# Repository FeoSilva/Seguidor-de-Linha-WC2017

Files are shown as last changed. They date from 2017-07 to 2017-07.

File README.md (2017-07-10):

# Marcos John - Seguidor-de-Linha-WC2017
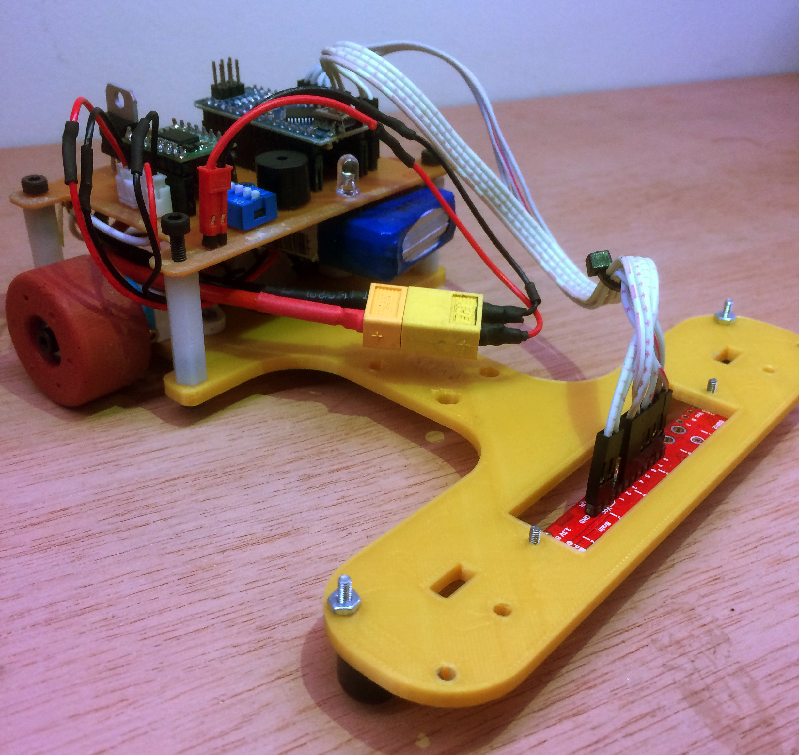
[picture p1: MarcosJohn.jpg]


O robô do Seguidor de Linha que participou do Winter Challenge edição 13 em 2017 está dividido em:
- Mecânica (Arquivos em CADs do robô projetado no SolidWorks 2016)
- Eletrônica (PCB projetada no Autodesk Eagle e confeccionada com a CNC OtherMill)
- Software (Programação do robô feita na IDE do Arduino)

Componentes do robô:
- Arduino Nano (Microcontrolador)
- <a href="https://www.pololu.com/product/960">QTR Array Analógico - Pololu (Sensor para Seguir Linha)</a>
- <a href="https://www.pololu.com/product/713">TB6612FNG - Pololu (Driver do Motor) </a>
- <a href="https://www.pololu.com/product/1098">50:1 Micro Metal Gearmotor LP 6V (Motores)</a>
- Bateria Li-Po 2S 7.4 - Turnigy

Agradecimentos: <br>
<a href="https://github.com/marcosdeoliveira">Marcos Oliveira</a><br>
<a href="https://github.com/joaopedrovbs">João Pedron Vilas Boas</a>

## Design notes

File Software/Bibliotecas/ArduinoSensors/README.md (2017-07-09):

# Arduino-Sensors

A "Library" of Libraries of Sensors. Infrared, Ultrasonic, Compass and many others,
ready to work with [ArduinoThread](https://github.com/ivanseidel/ArduinoThread) and fully object oriented.

This library was made to provide lot's of out-of-the-box features, such as 'Interfaces', 'Threadable' sensors,
and reliability over C++ Objects.

If you are a developer, please consider developing more sensor Libraries following the given pattern. I will be
pleased to incorporate it to the library!

## Installation

1. [Download](https://github.com/ivanseidel/ArduinoSensors/archive/master.zip) the Latest release from gitHub.
2. Unzip and modify the Folder name to "ArduinoSensors" (Remove the '-version')
3. Paste the modified folder on your Library folder (On your `Libraries` folder inside Sketchbooks or Arduino software).
4. Download and Install [ArduinoThread](https://github.com/ivanseidel/ArduinoThread)
5. Restart the Arduino IDE

## Included Generic Classes:

* AnalogIn
* DigitalIn
* DigitalOut
* AnalogVoltage

## Included Sensor Classes:

* MLX90614 Temperature Sensor
* HMC6352 Compass sensor
* EZ Ultrasonic Sensor
* Ping Ultrasonic Sensor
* HC-SR04 Ultrasonic Sensor
* InvenSense IMU MPU9150
* InvenSense IMU MPU6050
* Sharp Infrared Short Distance Sensor (GP2D120XJ00F)
* Sharp Infrared Medium Distance Sensor (GP2Y0A21YK)
* Sharp Infrared Long Distance Sensor (GP2Y0A02YK0F)

# The Concept of this Library

If you are here, you are probably looking for some sensor library. Perhaps an Distance sensor, or a Compass sensor, or even a IMU sensor. What do they all have in common? They are all sensors, and do some measurement. Perhaps an Angle, or a Distance, or a Speed...

Some libraries uses functions and others use Classes witch are better to maitain and even to understand the code. This Library tries to create a patterns that allows others to create better Sensor libraries with it, while keeping method names generic and compatibility across multiple platforms. Also, Sensors extend from it's base the a Thread (from [ArduinoThread](https://github.com/ivanseidel/ArduinoThread) Library), allowing `async` fetch of sensor data pretty easily.

But to do all that, we must have a strong and nice Base to work with. For example: There are many platforms that are 3.3v, 5v and even 1.8V. How can we make it work with multiple ADC values? How can we make it simple to develop and to use? Continue reading and you will understand.

# Base Classes

Consists of a set of classes that helps another classes like `DigitalIn`, `AnalogIn`, `DigitalOut`, `AnalogVoltage`. 

Also contains a set of Interfaces such as `AngleInterface`, `DistanceInterface`, `TemperatureInterface`, `VoltageInterface`, used by different sensor types.

Let's say we have a new Temperature sensor, and we want to create a Library for it. What we expect to have:
* **Generic method names.** In this case, it would extend a `TemperatureInterface`, that has the method `getTemperature` and `readTemperature`
* **Caching it's value.** We should be able to both `read` it's value (actually fetch sensor data, read analog, communicate...), or `get` it's current value (basically, return what was read last, like a caching).
* **Work Asynchronously.** Implementing Thread from [ArduinoThread](https://github.com/ivanseidel/ArduinoThread) Library, we can make it read with a fixed timing, and  get it's value latter without further delay.

## Interfaces

Interfaces are a very good way of transforming your usual code into a more generic way. It's basicaly a set of methods and properties (variables), that a Class will inherit. For example, every class that extends `AngleInterface`, will have a method called `readAngle` and `getAngle`. If a new sensor library is created, that reads an angle (perhaps a potentiometer, Compass or even a encoder), it could inherit from this interface, and get those methods.

I will explain why it's good to use with an experience I had:

I was developing a complex robot, that would require multiple Distance Sensor types. That included two types of Infrared distance sensor, and one type of Ultrasonic sensor. I have developed this library thinking that whenever I needed, I could change the sensor in hardware for another, and it would still work. Shure that there are physical differences between them, but what I wanted was to work with multiple sensors without altering more than ONE line of code. I so I did it. We could test with different sensors, without taking so much time on software and also hardware.

We also used a IMU from Invensense, that has a Compass. After a while, we decide to change that for a simple Compass Sensor. Both of the sensors libraries was made by me, implementing it's `AngleInterface`.

## Base Classes

Base Classes are used by other classes, and also by you (if you want), providing a even more High Level approach for IO manipulation.

### DigitalIn Class

Provides a easy approach for manipulating a Digital Input pin:

```
DigitalIn myButton(9);

// Check if Pin is HIGH
if (myButton)...
  
// Check if Pin is LOW
if (myButton == LOW)...

// Reads it's value
boolean val = myButton.readValue();

// Get last read value
val = myButton.getValue();
```

Also, if you initialize it passing `true` as a seccond param, every read will be inverted:
```
DigitalIn myInvertedButton(10, true);

// Check if Pin is LOW
if(myInvertedButton)

// Read it's value (inverted)
myInvertedButton.readValue();
```

### DigitalOut Class

Used to manipulate Digital Output pins in a easy way.

```
DigitalOut myLed(13);

// Turns LED on
myLed = HIGH;
myLed.turn(HIGH);
myLed.turnOn();

// Turns LED off
myLed = LOW;
myLed.turn(LOW);
myLed.turnOff();
```

Like DigitalIn, if you assign an seccond parameter in it's initialization, it will automatically invert it's output
```
DigitalOut myLedInverted(13, true);

// Turns LED off
myLedInverted = HIGH

// You can also check it's istate like this:
if(myLedInverted == HIGH) ...
```

### AnalogIn Class

We usually need to use Analog Pins as Digital. Or even Read it's value multiple times. I usually consider a lot the timing of things, knowing every milisecond that is happening on my program. Because of that you might consider using this class instead of usual `analogRead` function.

```
AnalogIn myPot(A0);

// Reads it's value
val = myPot.read();

// Get it's cached value (does not reads ADC, only returns last value)
val = myPot.getValue();
```

One usual case, is setting a threshold to compare. We do it for you:

```
// Set threshold for 500
myPot.setThreshold(500);

// Check if below 500
if(myPot.belowThreshold())...

if(myPot == false)...

// Check if above 500
if(myPot.aboveThreshold())...

if(myPot == true)...
```

## AnalogVoltage Class

This is a nice step for next generations of Libraries, because there are many Analog Sensors around, that it's converted value should be mapped to a Voltage, not a ADC value. But that's a problem becoming larger today, since there are platforms that runs with 5v, others with 3.3v... And imagine, every single library thrying to work whit that (or not)?

```
AnalogVoltage myVoltimeter(A0);

// Read the voltage (in Volts)
float pinVoltage = myVoltimeter.readVoltage();
```

Well, you might be wondering: How does it do it's magic? The answer is pretty simple: **Preprocessor macros**.

In compiling time, we detect weather you are using a 3.3v or 5v platform, and set a definition called `ADC_DEFAULT_AREF`. We use it later to scale the ADC to a voltage. But keep calm, you can override that pretty easily, and allows you to create custom `linear` voltage in readers (Like a voltage divider, to read a battery voltage).

```
// 0 in ADC now means -5v. full ADC (1024) means 10v
AnalogVoltage myCustomVoltimeter(A0, -5, 10);

float pinVoltage = myCustomVoltimeter.readVoltage();
```

# Working toguether with ArduinoThread

Read more about [ArduinoThread](https://github.com/ivanseidel/ArduinoThread) here. It's a library I created to simplify complex softwares that requires multiple async tasks. Let's say:
* Read Compass every 50ms
* Read Distance Sensors every 70ms
* Read a button every 5ms
* Get battery voltage every 1 minute
* and so on...

If you want a REAL example of it working, take a look at our [2013 RoboCup Junior Soccer Robot code](https://github.com/ivanseidel/Robot-Soccer-2013/tree/master/Software/Soccer_v02).

The idea is that you can register Threads in ThreadController (a group of Threads), and let the system check if it should be runned. In that way, you just GET sensor values in your main code, without consuming time every time you need something.

```
// Create a new ThreadController that will run always
// (means it will check if it's threads should be runned everytime)
ThreadController threads(0);

// Create some sensors
DistanceInterface *myDist1 = new SharpLong(A0);
DistanceInterface *myDist2 = new SharpShort(A1);
TemperatureInterface *thermometer = new MLX90614(0x32);
AngleInterface *myCompass = new HMC6352();

// Each sensor has it's interval set to minimum possible
// or something good to work with (20ms - 70ms).

// But they ARE Thread objects, so you can make use of
// it's methods:

// Compass should be read every 60ms
myCompass.setInterval(60);

// Add to the thread controller
threads.add(&myDist1);
threads.add(&myDist2);
threads.add(&thermometer);
threads.add(&myCompass);

// Now, just call threads.run(); to automatically run what is needed
// (perhaps in a Timer Callback? or in Loop.. whatever)
loop(){
  threads.run();
  
  // Get the most recend value WITHOUT reading the sensor
  double currentAngle = myCompass->getAngle();
  float distance = myDist1->getDistance();
  [...]
}

```

## Rest of Documentation under development...

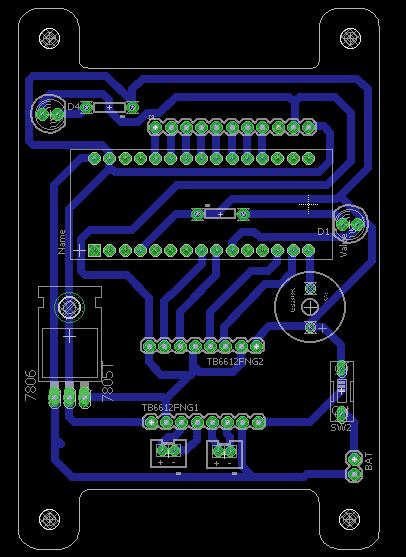
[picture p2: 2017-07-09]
Midia/PCB.JPG

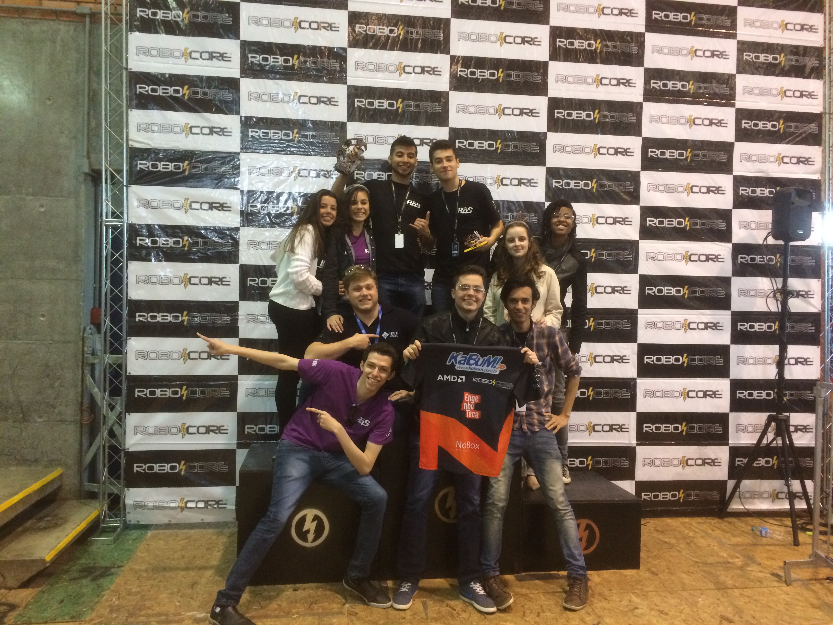
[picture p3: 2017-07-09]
Midia/Arquivo_001.jpeg

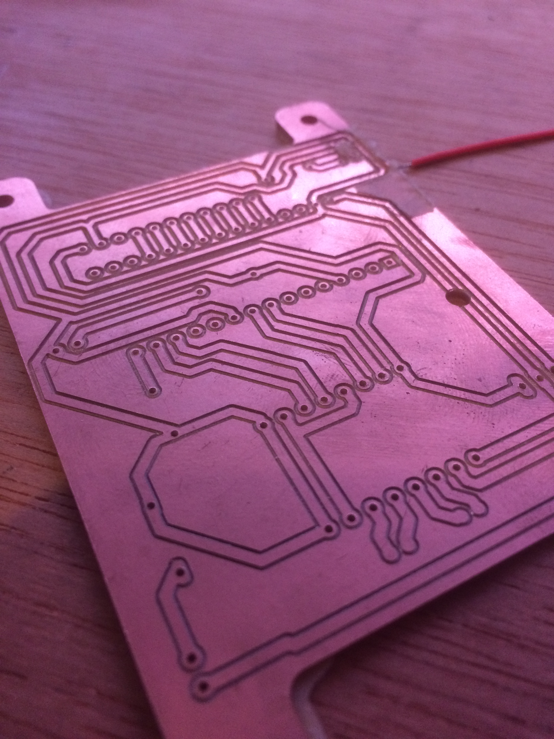
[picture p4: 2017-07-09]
Midia/Arquivo_000.jpeg

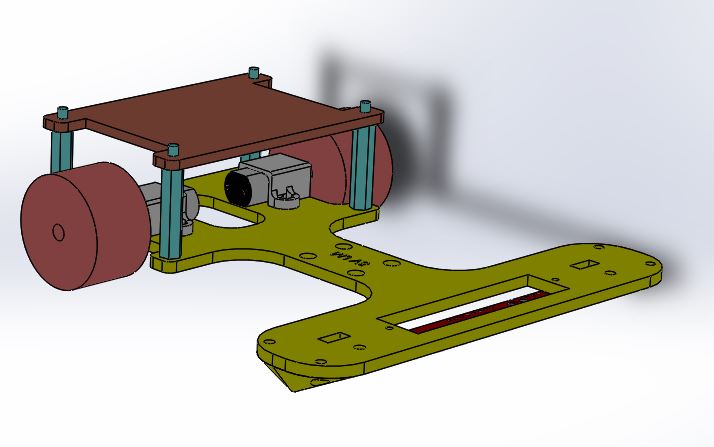
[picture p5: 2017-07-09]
Midia/Robot-3D.JPG

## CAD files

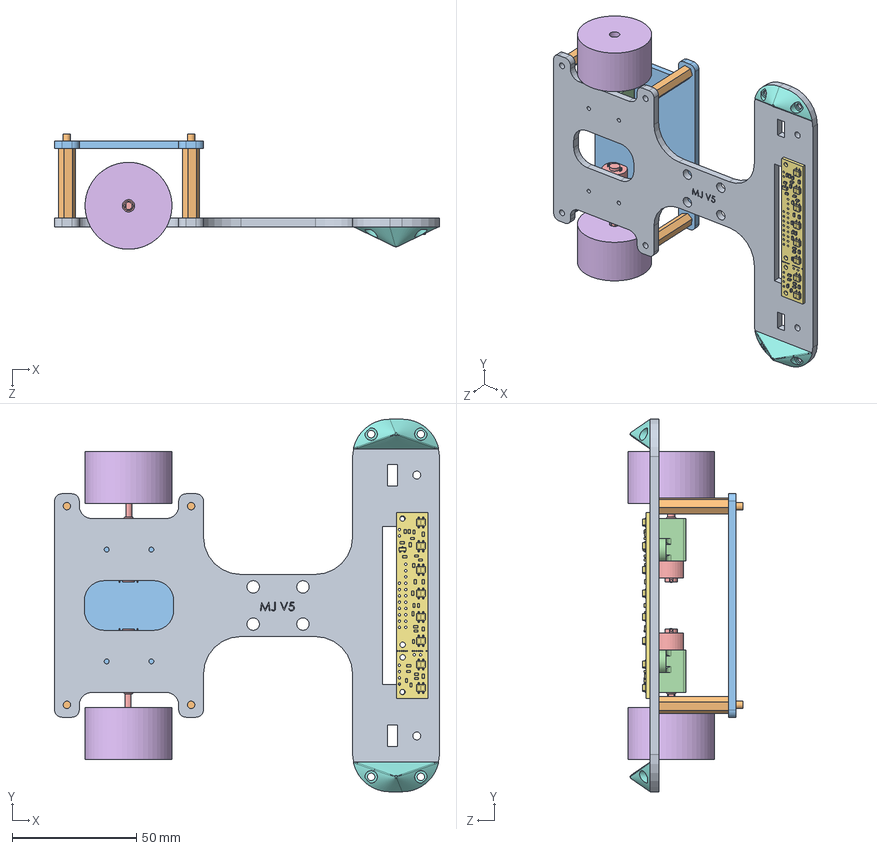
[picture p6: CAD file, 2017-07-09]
Mecânica/MJ V5/Robo completo.SLDASM
155.0 x 150.0 x 46.5 mm
PrincipalN
Standoff-Nylon x 4
PCB
Bracket Pololu x 2
Pololu #2218 Micro Metal Gearmotor HP(1) x 2
Rodas x 2
array oficial
ApoioN x 2

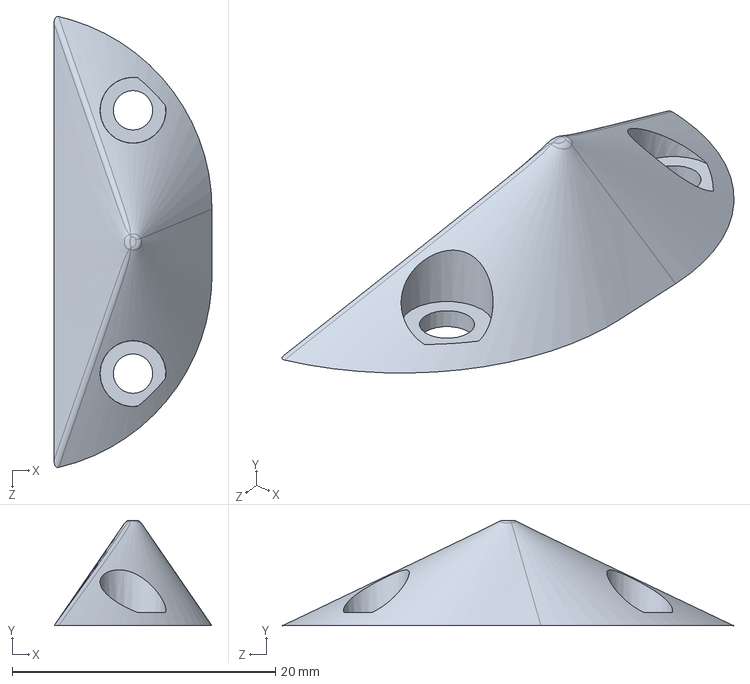
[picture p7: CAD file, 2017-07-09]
Mecânica/MJ V5/ApoioN.SLDPRT
12.0 x 8.00 x 34.3 mm

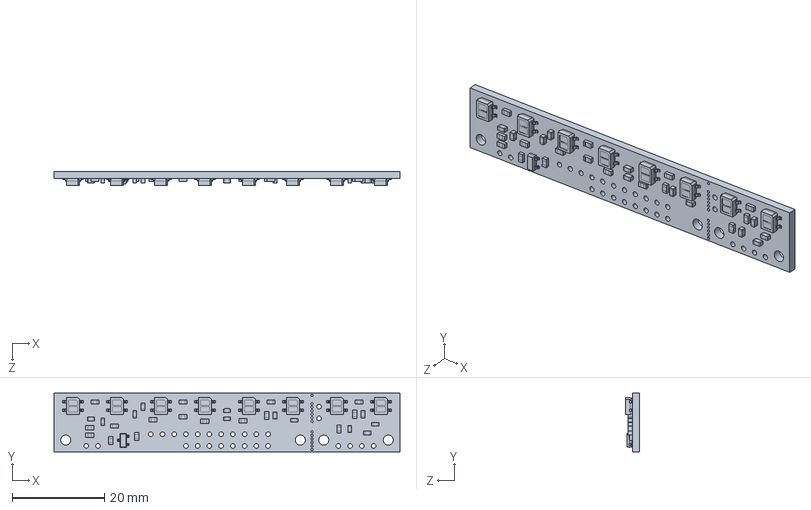
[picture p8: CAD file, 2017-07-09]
Mecânica/MJ V5/array oficial.SLDPRT
74.9 x 12.7 x 3.07 mm

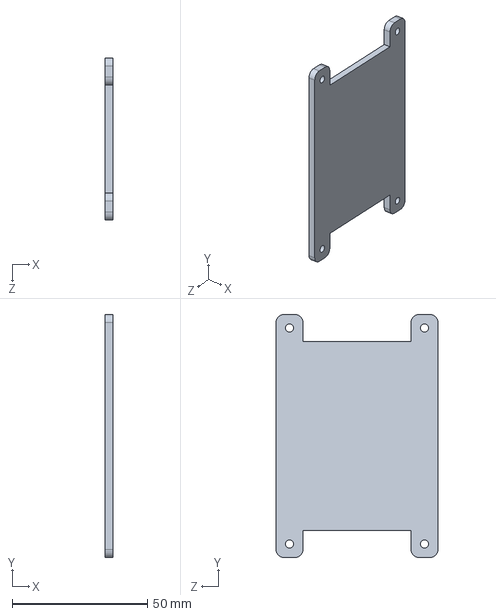
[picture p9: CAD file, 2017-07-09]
Mecânica/MJ V5/PCB.SLDPRT
3.00 x 90.0 x 60.0 mm

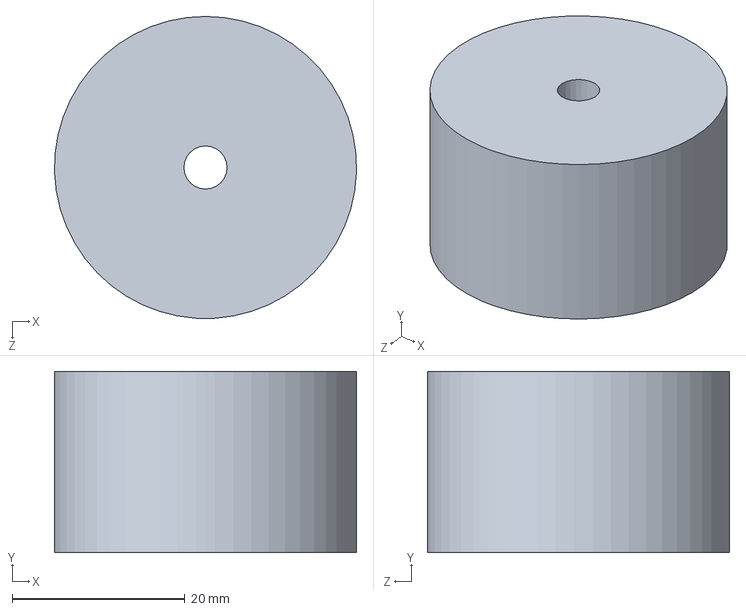
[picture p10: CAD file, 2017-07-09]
Mecânica/MJ V5/Rodas.SLDPRT
35.0 x 21.0 x 35.0 mm

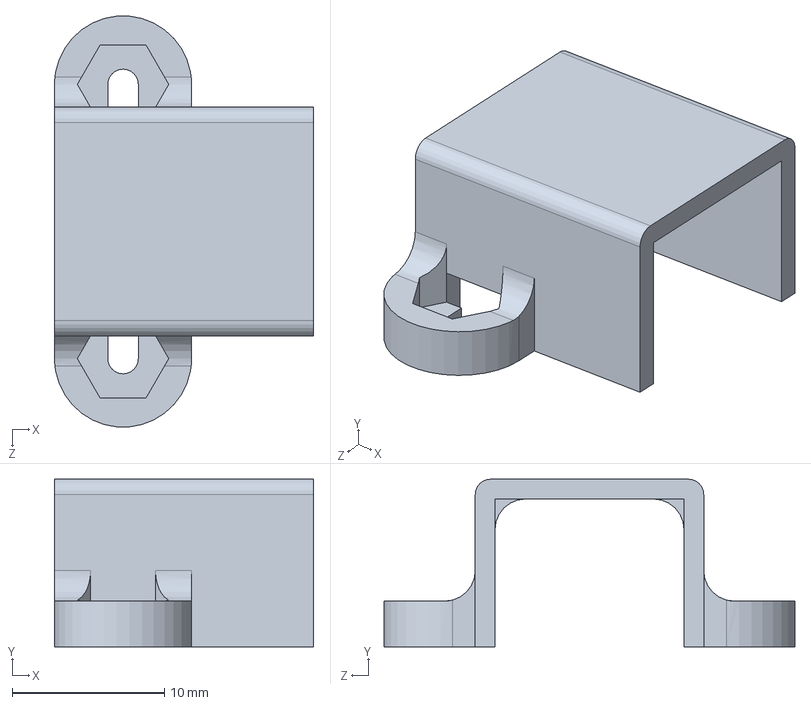
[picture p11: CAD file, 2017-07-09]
Mecânica/MJ V5/Bracket Pololu.SLDPRT
17.0 x 11.0 x 27.0 mm

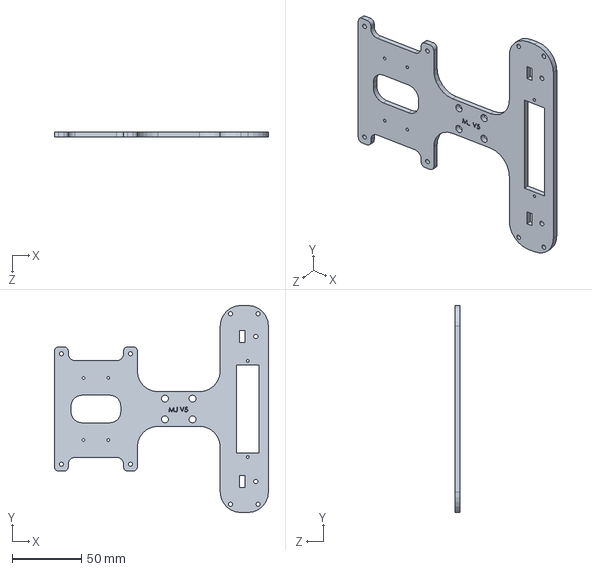
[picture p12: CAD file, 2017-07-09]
Mecânica/MJ V5/PrincipalN.SLDPRT
155.0 x 150.0 x 3.50 mm

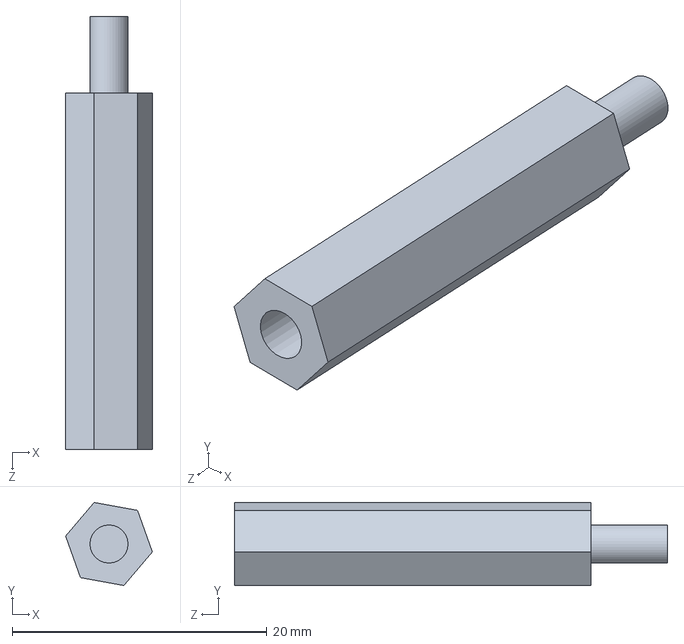
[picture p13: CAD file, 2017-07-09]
Mecânica/MJ V5/Standoff-Nylon.SLDPRT
6.82 x 6.52 x 34.0 mm

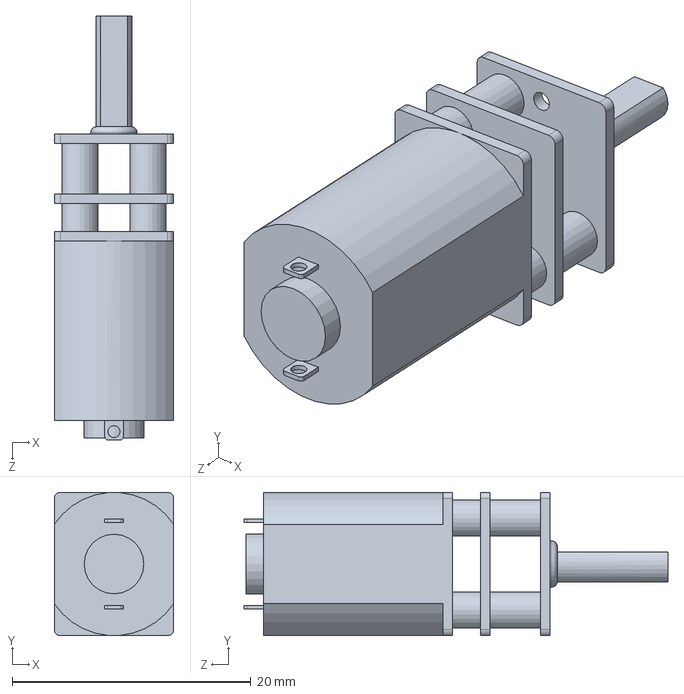
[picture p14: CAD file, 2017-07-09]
Mecânica/MJ V5/Pololu #2218 Micro Metal Gearmotor HP(1).SLDPRT
10.0 x 12.0 x 35.5 mm

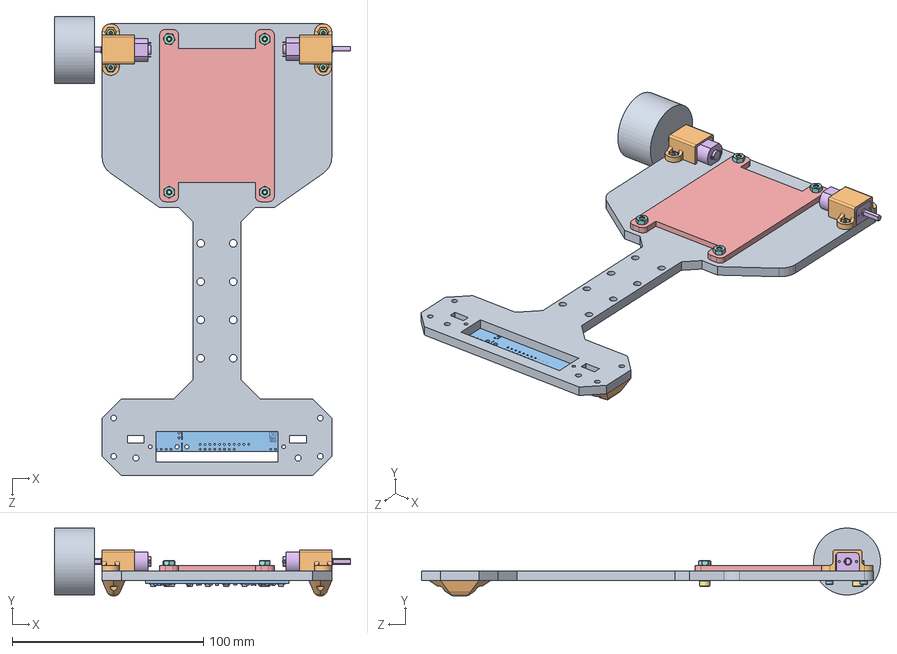
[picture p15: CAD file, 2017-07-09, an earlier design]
Mecânica/MJ V4/Montagem1.SLDASM
154.9 x 35.5 x 239.8 mm
Principal
Bracket Pololu x 2
M2 x 0.4mm Thread 8mm LONG SOCKET HEAD CAP SCREW x 4
M2 x 0.4mm Thread HEX NUT x 4
PCB
Pololu #2218 Micro Metal Gearmotor HP x 2
M3 x 0.5mm Thread 10mm LONG SOCKET HEAD CAP SCREW x 4
M3 x 0.5mm Thread HEX NUT x 4
Rodas
Apoio x 2
array oficial

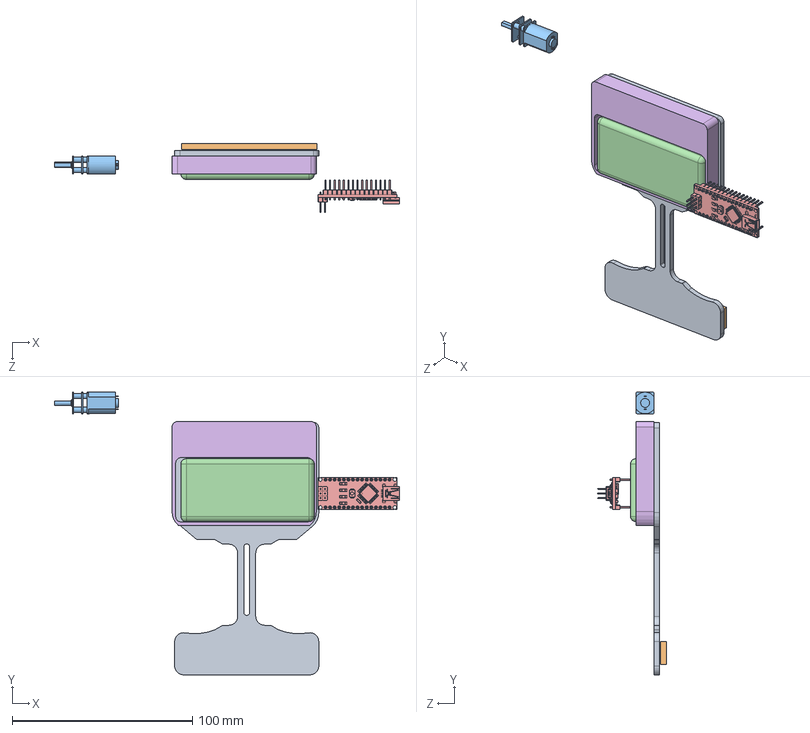
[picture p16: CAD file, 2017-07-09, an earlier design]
Mecânica/MJ V1/Montagem1.SLDASM
191.3 x 156.8 x 38.0 mm
LinhRaS
MicroMotor
Lipo
ArduinoNano
suporte

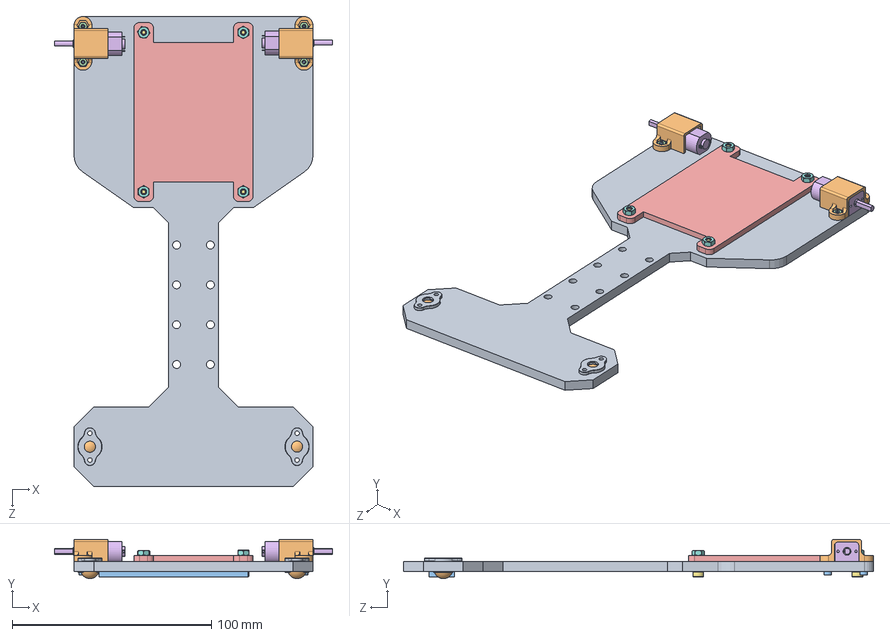
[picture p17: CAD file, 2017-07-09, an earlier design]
Mecânica/MJ V2/Montagem1.SLDASM
139.7 x 19.7 x 236.0 mm
Principal
Bracket Pololu x 2
M2 x 0.4mm Thread 8mm LONG SOCKET HEAD CAP SCREW x 4
M2 x 0.4mm Thread HEX NUT x 4
PCB
Pololu #2218 Micro Metal Gearmotor HP x 2
M3 x 0.5mm Thread 10mm LONG SOCKET HEAD CAP SCREW x 4
M3 x 0.5mm Thread HEX NUT x 4
Caster_1 x 2
Ball x 2

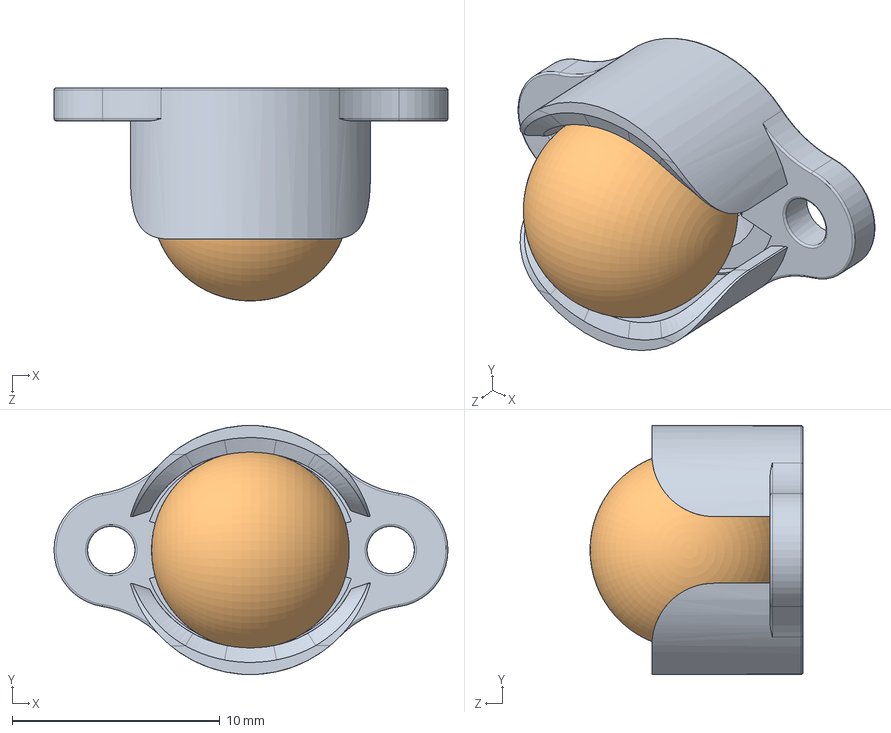
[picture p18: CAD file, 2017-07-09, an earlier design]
Mecânica/MJ V4/Pololu Ball Caster with 3_8_ Metal Ball.SLDASM
19.0 x 12.0 x 10.3 mm
Caster_1
Ball

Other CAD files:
Mecânica/MJ V3/Ball.sldasm
Mecânica/MJ V2/Ball.sldasm
Eletrônica/Eletronica V1/PCB Size.DXF
Eletrônica/Eletronica V1/Placa principal_N.cmp.dxf
Eletrônica/Eletronica V1/Placa principal_N.sol.dxf
Mecânica/MJ V1/ArduinoNano.SLDPRT
Mecânica/MJ V1/LinhRaS.SLDPRT
Mecânica/MJ V1/Lipo.SLDPRT
Mecânica/MJ V1/NanoV3 v4.step
Mecânica/MJ V1/suporte.SLDPRT
Mecânica/MJ V2/Allen_M3x10.stl
Mecânica/MJ V2/Array.SLDPRT
Mecânica/MJ V2/Ball.sldprt
Mecânica/MJ V2/Bracket Pololu.SLDPRT
Mecânica/MJ V2/M2/M2 screw size FLAT WASHER.SLDPRT
Mecânica/MJ V2/M2/M2 x 0.4mm Thread 10mm LONG SOCKET HEAD CAP SCREW.SLDPRT
Mecânica/MJ V2/M2/M2 x 0.4mm Thread 12mm LONG SOCKET HEAD CAP SCREW.SLDPRT
Mecânica/MJ V2/M2/M2 x 0.4mm Thread 14mm LONG SOCKET HEAD CAP SCREW.SLDPRT
Mecânica/MJ V2/M2/M2 x 0.4mm Thread 16mm LONG SOCKET HEAD CAP SCREW.SLDPRT
Mecânica/MJ V2/M2/M2 x 0.4mm Thread 18mm LONG SOCKET HEAD CAP SCREW.SLDPRT
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

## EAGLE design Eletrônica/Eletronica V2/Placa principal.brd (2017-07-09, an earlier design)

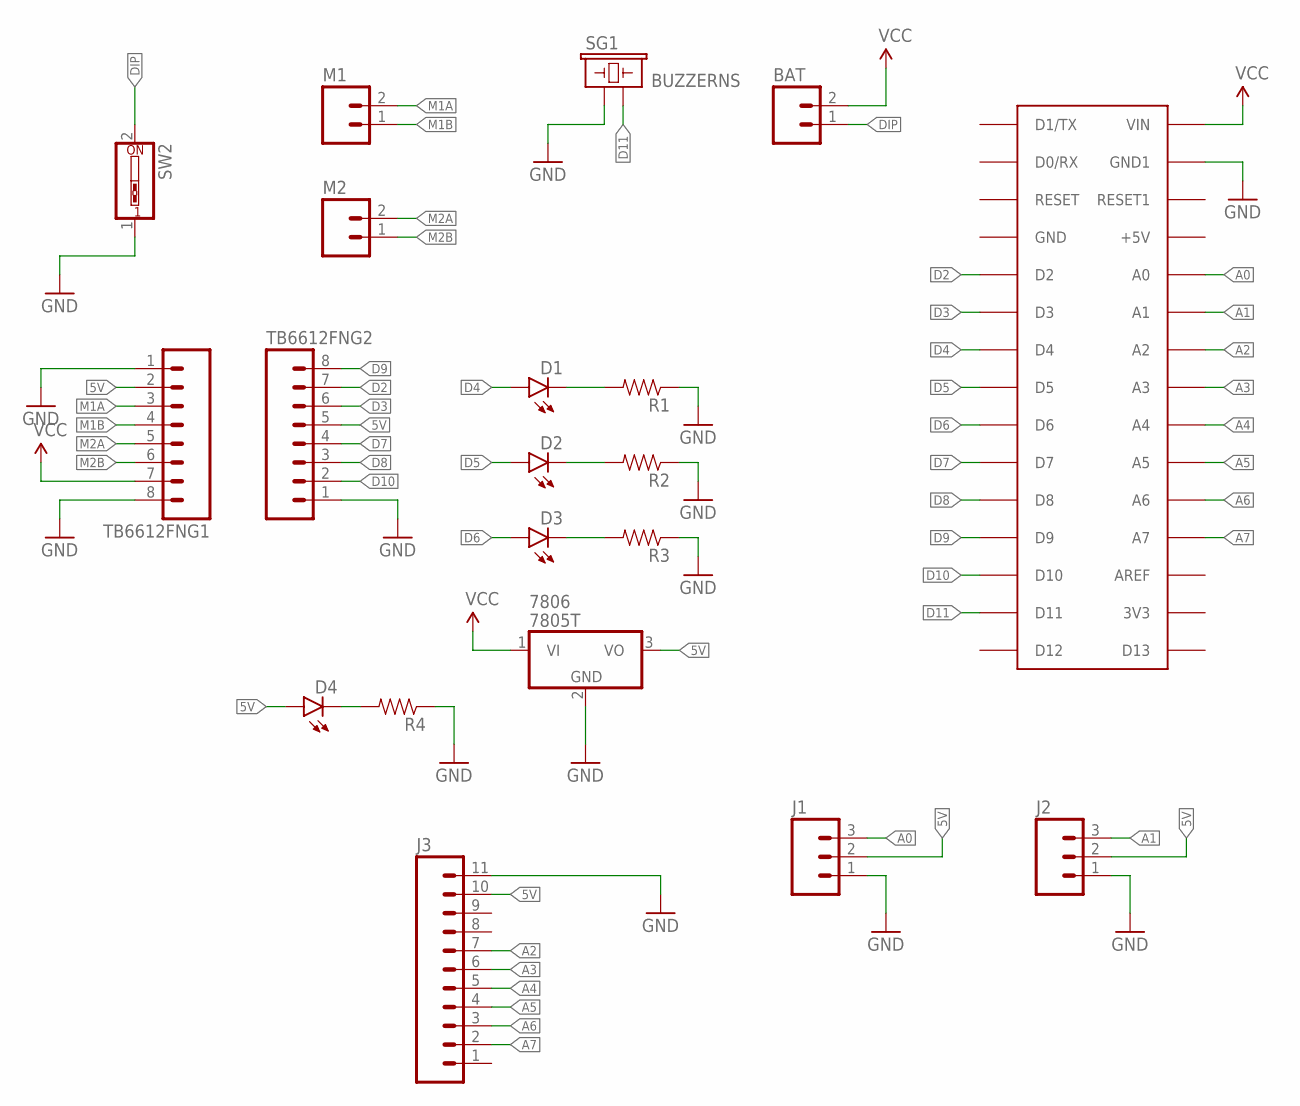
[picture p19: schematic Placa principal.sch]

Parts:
7806: 7805T; TO220H
BAT: M02PTH; 1X02
D1, D2, D3, D4: LED5MM
J1, J2: M03PTH; 1X03
J3: M11PTH; 1X11
M1, M2: M02JST-PTH-VERT; JST-2-PTH-VERT
R1, R2, R3, R4: RESISTOREZ; AXIAL-0.3EZ
SG1: BUZZERNS; BUZZER-12MM-NS
SW2: SW_DIP-1; EDG-01
TB6612FNG1, TB6612FNG2: M08; 1X08_ROUND
U$2: ARDUINONANO; PDIP-32

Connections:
5V: 7806.3 (VO), D4.A, J1.2, J2.2, J3.10, TB6612FNG1.2, TB6612FNG2.5
A0: J1.3, U$2.A0
A1: J2.3, U$2.A1
A2: J3.7, U$2.A2
A3: J3.6, U$2.A3
A4: J3.5, U$2.A4
A5: J3.4, U$2.A5
A6: J3.3, U$2.A6
A7: J3.2, U$2.A7
D2: TB6612FNG2.7, U$2.D2
D3: TB6612FNG2.6, U$2.D3
D4: D1.A, U$2.D4
D5: D2.A, U$2.D5
D6: D3.A, U$2.D6
D7: TB6612FNG2.4, U$2.D7
D8: TB6612FNG2.3, U$2.D8
D9: TB6612FNG2.8, U$2.D9
D10: TB6612FNG2.2, U$2.D10
D11: SG1.- (2), U$2.D11
DIP: BAT.1, SW2.2
GND: 7806.2 (GND), J1.1, J2.1, J3.11, R1.P$1 (1), R2.P$1 (1), R3.P$1 (1), R4.P$1 (1), SG1.+ (1), SW2.1, TB6612FNG1.1, TB6612FNG1.8, TB6612FNG2.1, U$2.GND1
M1A: M1.2, TB6612FNG1.3
M1B: M1.1, TB6612FNG1.4
M2A: M2.2, TB6612FNG1.5
M2B: M2.1, TB6612FNG1.6
unnamed: D4.K (C), R4.P$2 (2)
unnamed: D1.K (C), R1.P$2 (2)
unnamed: D2.K (C), R2.P$2 (2)
unnamed: D3.K (C), R3.P$2 (2)
VCC: 7806.1 (VI), BAT.2, TB6612FNG1.7, U$2.VIN

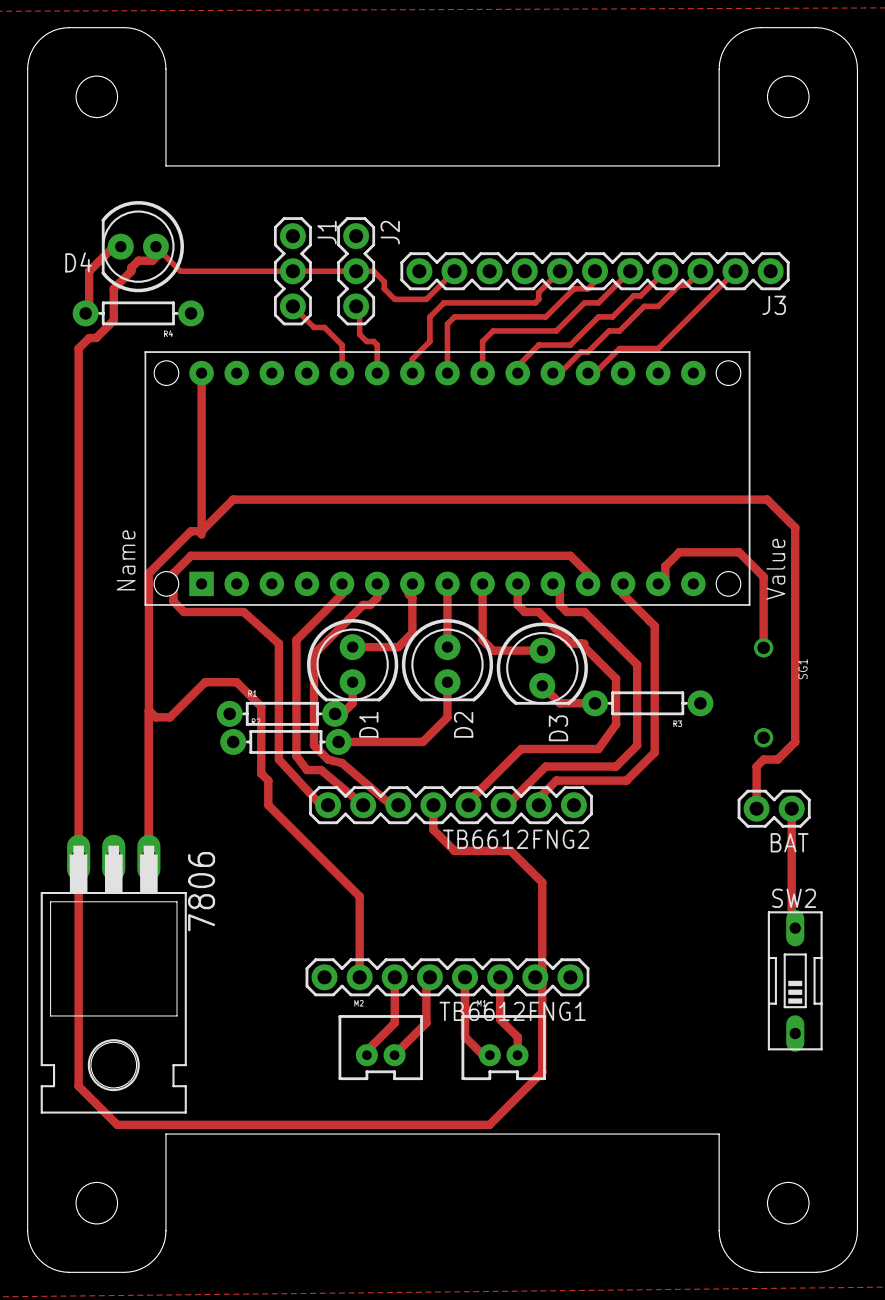
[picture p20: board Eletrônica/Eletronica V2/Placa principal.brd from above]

Board: 2 copper layers, 60.0 x 90.0 mm, 20 parts (0 on the bottom side), 30 nets.

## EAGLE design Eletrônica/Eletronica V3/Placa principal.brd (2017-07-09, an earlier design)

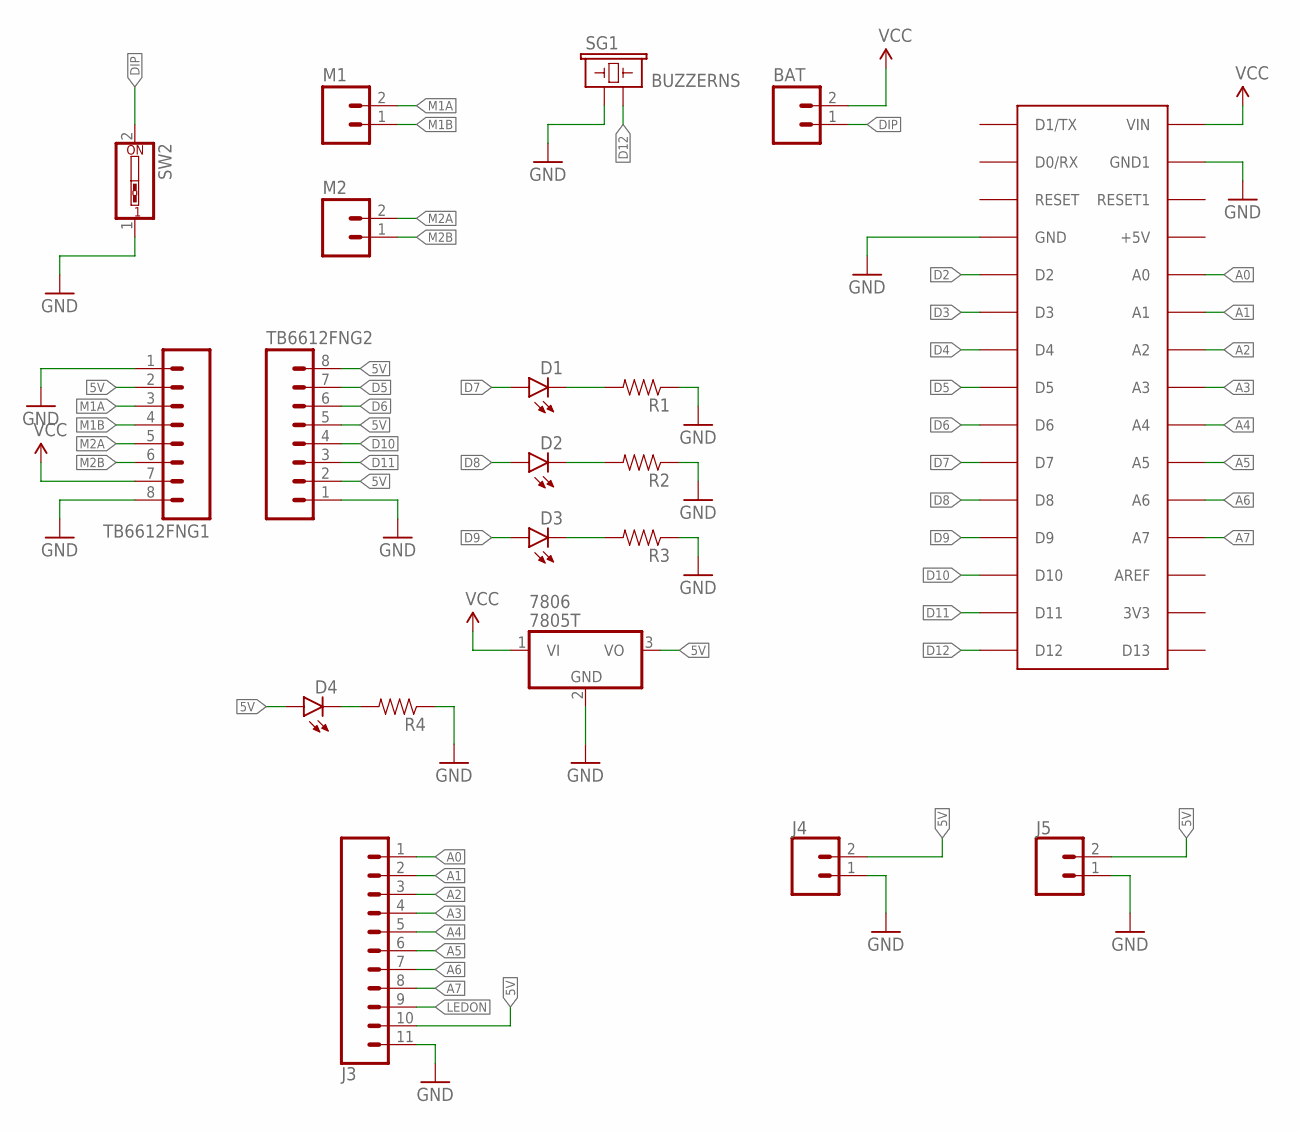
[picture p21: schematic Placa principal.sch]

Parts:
7806: 7805T; TO220H
BAT: M02PTH; 1X02@1
D1, D2, D3, D4: LED5MM
J3: CONN_11; 1X11
J4, J5: CONN_02; 1X02
M1, M2: M02JST-PTH-VERT; JST-2-PTH-VERT
R1, R2, R3, R4: RESISTOREZ; AXIAL-0.3EZ
SG1: BUZZERNS; BUZZER-12MM-NS
SW2: SW_DIP-1; EDG-01
TB6612FNG1, TB6612FNG2: M08; 1X08_ROUND
U1: NANO; PDIP-32

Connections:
5V: 7806.3 (VO), D4.A, J3.10, J4.2, J5.2, TB6612FNG1.2, TB6612FNG2.2, TB6612FNG2.5, TB6612FNG2.8
A0: J3.1, U1.A0
A1: J3.2, U1.A1
A2: J3.3, U1.A2
A3: J3.4, U1.A3
A4: J3.5, U1.A4
A5: J3.6, U1.A5
A6: J3.7, U1.A6
A7: J3.8, U1.A7
D2: U1.D2
D3: U1.D3
D4: U1.D4
D5: TB6612FNG2.7, U1.D5
D6: TB6612FNG2.6, U1.D6
D7: D1.A, U1.D7
D8: D2.A, U1.D8
D9: D3.A, U1.D9
D10: TB6612FNG2.4, U1.D10
D11: TB6612FNG2.3, U1.D11
D12: SG1.- (2), U1.D12
DIP: BAT.1, SW2.2
GND: 7806.2 (GND), J3.11, J4.1, J5.1, R1.P$1 (1), R2.P$1 (1), R3.P$1 (1), R4.P$1 (1), SG1.+ (1), SW2.1, TB6612FNG1.1, TB6612FNG1.8, TB6612FNG2.1, U1.GND, U1.GND1
LEDON: J3.9
M1A: M1.2, TB6612FNG1.3
M1B: M1.1, TB6612FNG1.4
M2A: M2.2, TB6612FNG1.5
M2B: M2.1, TB6612FNG1.6
unnamed: D4.K (C), R4.P$2 (2)
unnamed: D1.K (C), R1.P$2 (2)
unnamed: D2.K (C), R2.P$2 (2)
unnamed: D3.K (C), R3.P$2 (2)
VCC: 7806.1 (VI), BAT.2, TB6612FNG1.7, U1.VIN

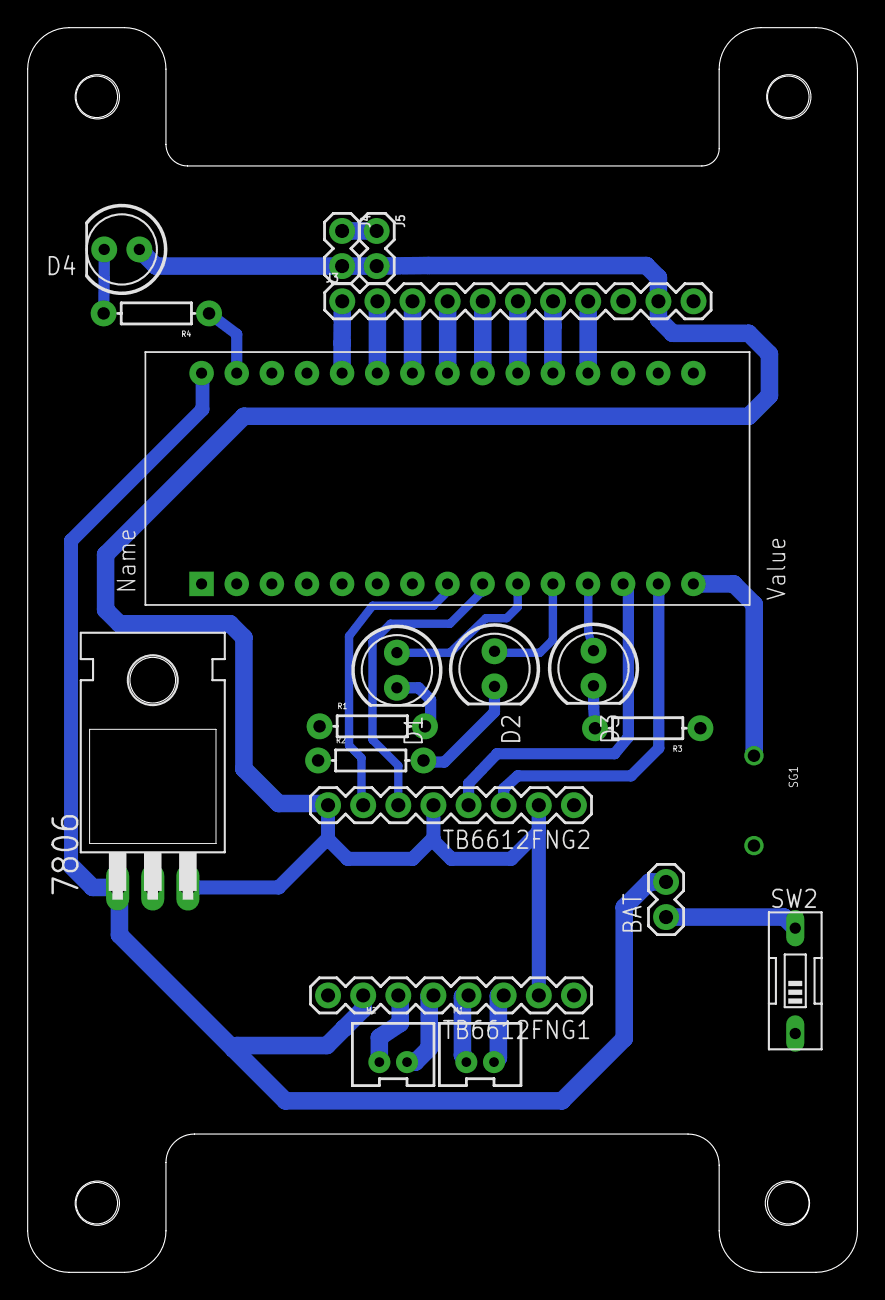
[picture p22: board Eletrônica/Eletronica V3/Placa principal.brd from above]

Board: 2 copper layers, 60.0 x 90.0 mm, 20 parts (0 on the bottom side), 28 nets.

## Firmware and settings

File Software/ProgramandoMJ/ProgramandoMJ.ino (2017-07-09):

/*
 * Programacao para o torneio Winter Challenge 2017
 * Desenvolvido por Felipe Silva, Felipe Tiozo, Yasmin Ribeiro, Kherollyn Alencar
 * Equipe Tamandutech (RAS UFABC)[Think Team] {Project Neon}
 * Apoio: 
 * http://facebook.com/IEEERASUFABC
 * https://www.facebook.com/ThinkTeamBR/
 * https://www.facebook.com/tamandutech/
 */

#include <QTRSensors.h>

#include "Wire.h"
#include <Thread.h>
#include "AnalogIn.h"
#include "DigitalIn.h"
#include "DigitalOut.h"
#include <ArduinoSensors.h>
#include <sensors/AnalogVoltage.h>

/// Basic robot definitions
#include "Config.h"

#include "Readings.h" // lê
#include "Actions.h" // age
#include "Controllers.h" // controla


void setup() {
  
  Serial.begin(9600);

  // SETUP DE TUDO
  ligarMotores(); // ligar motores
  
  AlertaDeInicio();
  delay(500); 
    
  Serial.println("Calibration Run");
  Serial.println("Calibration Running...");
  
  for (int i = 0; i < 100; i++)  // make the calibration take about 10 seconds
  {
    Buzzer.turnOn();
    qtra.calibrate();       // reads all sensors 10 times at 2500 us per read (i.e. ~25 ms per call)
    Buzzer.turnOff();
    delay(10);
  }
  
  LED3.turnOff();
  Serial.println("Calibration Done!");
  
  // Mostrar 'Inicializando...'
  Serial.println("Inicializando...");
  delay(800);
  
  tempoinicial = millis();
  Serial.println(tempoinicial);
  
}

void loop() {

    //Serial.println(lerTodosQTR());
  
    //lerTodosSensores();

    // Funcao que roda o seguidor de linha ate ele parar
    Seguidor(true);
    
}

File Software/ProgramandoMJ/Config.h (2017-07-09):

#include <Arduino.h>

/*
  ROBOT GENERAL CONFIGURATION
*/

/************************ MOTORES ************************/
// Motores: Pololu 30:1 Micro Motor MP 6V

// Motor ESQUERDO DIANETEIRO
#define MotorEsquerdoFrente 6
#define MotorEsquerdoTras 5

// Motor DIREITO DIANTEIRO
#define MotorDireitoFrente 10
#define MotorDireitoTras 11


void ligarMotores() {
  // MOTOR ESQUERDO DIANTEIRO
  pinMode(MotorEsquerdoFrente, OUTPUT);
  pinMode(MotorEsquerdoTras, OUTPUT);

  
  // MOTOR DIREITO DIANTEIRO
  pinMode(MotorDireitoFrente, OUTPUT);
  pinMode(MotorDireitoTras, OUTPUT);

}

/************************ SENSORES ************************/
// Sensores: Pololu QTR-8A reflectance sensor
// PORTAS ANÁLOGICAS

// SENSORES ARRAY QTR-8-A
#define luminosidade1     A5 // SENSOR LINHA 1
#define luminosidade2     A4 // SENSOR LINHA 2
#define luminosidade3     A3// SENSOR LINHA 3
#define luminosidade4     A2 // SENSOR LINHA 4
#define luminosidade5     A1 // SENSOR LINHA 5
#define luminosidade6     A0 // SENSOR LINHA 6

#define luminosidade7    A6 // SENSOR ESQUERDA
#define luminosidade8     A7 // SENSOR DIREITA

int QTR[] = {
  0,
  luminosidade1,
  luminosidade2,
  luminosidade3,
  luminosidade4,
  luminosidade5,
  luminosidade6,
  luminosidade7,
  luminosidade8
    
};

// SETTINGS PARA LER O ARRAY COM A FUNÇÃO .readLine()
#define NUM_SENSORS             6  // number of sensors used
#define NUM_SAMPLES_PER_SENSOR  4  // average 4 analog samples per sensor reading

// Sensores de 0 a 8 que estão conectados nas portas analógicas
QTRSensorsAnalog qtra((unsigned char[]) {luminosidade1, luminosidade2, luminosidade3, luminosidade4, luminosidade5, luminosidade6}, 
  NUM_SENSORS, NUM_SAMPLES_PER_SENSOR);
unsigned int sensorValues[NUM_SENSORS];

 
/************************ INTERFACE ************************/

// LEDs para identificação de ações 
#define led1  7 // LED
#define led2  8 // LED
#define led3  9 // LED

int LEDs[] {
  0,
  led1,
  led2,
  led3
};

DigitalOut LED1(led1);
DigitalOut LED2(led2);
DigitalOut LED3(led3);


// Buzzer para fazer barulinho
#define buzzer 12
DigitalOut Buzzer(buzzer);


/************************ ESTADOS *********************/
#define ESQUERDA -1
#define DIREITA   1

#define CIMA 1
#define BAIXO 0
#define IDDLE   0

/************************ VARIÁVEIS DO ROBÔ ************************/
unsigned long tempoinicial = 0;
unsigned long int tempopercorrido = 0;
int tempofinal = 16000;

int erro; int P; int I; int D;
int ganho;
double motorB; 
double motorC;

int lastError = 0;

float KP = 0.03;
float KI = 0;
float KD = 0.89;

int forcaPID = 68;

int forcaReta = 78;

int setPoint = 2500;

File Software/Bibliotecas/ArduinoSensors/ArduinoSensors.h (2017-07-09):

/*
 	ArduinoSensors.h - Main ArduinoSensor file.

 	Provides repetitive code in pretty functions

 	Include this file in order to allow the compiler to discover the sub
 	folders and files of ArduinoSensors Library

	For instructions, go to https://github.com/ivanseidel/Arduino-Sensors

	Created by Ivan Seidel Gomes, June, 2013.
	Released into the public domain.
*/


#ifndef ArduinoSensors_h
#define ArduinoSensors_h

#include <Arduino.h>

/*
	Simple conversion from float to String.

	float f: the float to be converted
	int decimals: number of decimal places
*/
String floatToString(float f, int decimals = 2){
	/*
		Transforms the floating point string process:
		eg.: using decimals = 2, input: 0.01
			1.23456 * (pow(10, 2+1)
				1.23456 * 1000 = 1234 (as a long)
			now, let's move digits asside:
			3 goes to 4, 2 goes to 3.
			Stages:		"1234"
						"1233"
						"1223"
			Not, put a dot in the place of the separator
			"1.23"

	*/
	long fLong = f*(pow(10,decimals+1));
	String longString = String(fLong);
	int len = longString.length();

	for(int i = 0; i < decimals; i++){
		longString[len - 1 - i] = longString[len - 2 - i];
	}
	longString[len - decimals - 1] = '.';

	return longString;
}

/*
	Convert an angle in Degrees to Radians
*/
float toRads(double angle){
	return angle * M_PI/180.0;
}

/*
	Convert an angle in Radians to Degrees
*/
float toDegs(double angle){
	return angle * 180.0/M_PI;
}

/*
	This function is usefull for fixing realtive angles.
	If you input anything from -180 to 180, it will return the same.

	However, if you input for example, 200, it will return -160
	Input |	Output
	0 		0
	180		180
	-180	-180
	181		-179
	-181	179
	360		0
	540		-180

*/
float fixDegrees(float angle){
	while (angle < -180.0)
		angle += 360.0;

	while (angle > 180.0)
		angle -= 360.0;

	return angle;
};


/*
	This is the same as the above, but working with Radians.
	(PI = 180; -PI = -180; 2*PI = 360)
*/
float fixRads(float angle){
	while (angle < - M_PI)
		angle += 2*M_PI;

	while (angle > M_PI)
		angle -= 2*M_PI;

	return angle;
};

/*
	Converts from inches to centimeters
*/
inline float toCentimeters(float inches){
	return inches * 0.393700787;
}

/*
	Converts from centimeters to inches
*/
inline float toInches(float centimeters){
	return centimeters * 2.54;
}


/*
	This preprocessor logic will determine the default
	AREF voltage for the current Arduino being compiled
*/
#if defined(__AVR__)
	
	/*
		AVR family usualy is 3.3v when running on 8Mhz,
		and 5.0 if running on 16Mhz
	*/	
	#if 	F_CPU <= 8000000
		#warning "ADC_DEFAULT_AREF = 3.3v | AVR <=8Mhz clock"
		#define ADC_DEFAULT_AREF	3.3
	#elif 	F_CPU <= 16000000
		#warning "ADC_DEFAULT_AREF = 5.0v | AVR >8Mhz & <=16Mhz clock"
		#define ADC_DEFAULT_AREF	5.0
	#else
		#warning "ADC_DEFAULT_AREF = 5.0v | AVR Default AREF"
		#define ADC_DEFAULT_AREF	5.0
	#endif

#elif defined(__PIC32MX__)

	/*
		Currently, all Arduinos with PIC32 are 3.3v
	*/
	#pragma message("ADC_DEFAULT_AREF = 3.3v | PIC32 Archtecture")
	#define ADC_DEFAULT_AREF		3.3

#elif defined(__arm__)

	/*
		Currently, all Arduinos with ARM are 3.3v
	*/
	#pragma message("ADC_DEFAULT_AREF = 3.3v | ARM Archtecture")
	#define ADC_DEFAULT_AREF		3.3	

#endif

#ifndef ADC_DEFAULT_AREF
	#warning "ADC_DEFAULT_AREF = 5.0v | Default value"
	#define ADC_DEFAULT_AREF		5.0
#endif

/*
	With tests, I could notice an average voltage output
	from the regulator of (VCC * (1 - 0.03)) as the output.

	An average of 3% drop is the normal.

	So we define that to fix some small erros.

	NOTE: This feature is disabled by default.
*/
// #define ADC_VOLTAGE_PROP	0.03
#define ADC_VOLTAGE_PROP	0.00

#endif

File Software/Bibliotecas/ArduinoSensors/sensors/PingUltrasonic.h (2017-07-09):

/*
	Ultrasonic.h - Library for Ping and HR-SC04 Ultrasonic Ranging Module.

	In order to use PING sensors (One wire for data only), use:
		PingUltrasonic myUltrasonic(dataPin);
	
	In order to use with two wire (Trigger and Echo) sensors, use:
		PingUltrasonic myUltrasonic(triggerPin, echoPin);


	Working range: 3 - 500

	For instructions, go to https://github.com/ivanseidel/Arduino-Sensors

	Modified by	Ivan Seidel Gomes, June, 2013.
	Released into the public domain.
*/

#ifndef Ultrasonic_h
#define Ultrasonic_h

#include <Arduino.h>

#include <Thread.h>
#include <interfaces/DistanceInterface.h>

class PingUltrasonic: public Thread, public DistanceInterface
{
private:
	int trigPin;
	int echoPin;

	long duration;
	float distance;

	void sendCommand(){
		// Set pin as output
		if(trigPin == echoPin)
			pinMode(trigPin, OUTPUT);

		// Make shure it's LOW (Erase state)
		digitalWrite(trigPin, LOW);
		delayMicroseconds(2);

		// Send pulse
		digitalWrite(trigPin, HIGH);
		delayMicroseconds(10);
		digitalWrite(trigPin, LOW);

		// Set pin as input
		if(trigPin == echoPin)
			pinMode(echoPin, INPUT);
	}

	bool waitResponse(){
		long startTime = micros();

		// Waits it to get HIGH
		while(digitalRead(echoPin) == LOW){
			if(micros() - startTime > 1000){
				return false;
				break;
			}
		}
		return true;
	}

public:
	PingUltrasonic(int _trigPin, int _echoPin = -1) : Thread(){
		trigPin = _trigPin;

		/*
			Ping sensors uses only one pin to trigger and echo
		*/
		if(echoPin < 0)
			echoPin = trigPin;
		else
			echoPin = _echoPin;

		pinMode(trigPin, OUTPUT);
		pinMode(echoPin, INPUT);

		minDistance = 3;
		maxDistance = 500;

		setInterval(50);
	}

	virtual float getDistance(){
		return distance;
	}

	virtual float readDistance(){
		// Send pulse to trigger reading action
		sendCommand();

		/*
			After reading, if this flag is true, indicates either:
				* Sensor is not connected (echo is not responding)
				* Timeout on reading pulse
		*/
		bool error = false;
		
		// Start time to compare later
		long startTime = micros();

		// Waits for the pulse, and check if returned true
		if(waitResponse()){
		
			// Reads HIGH pulse time
			while(digitalRead(echoPin) == HIGH){
				if(micros() - startTime > 50000){
					error = true;
					// Serial.println("FAIL2!");
					// Serial.print("FAIL2!\t");
					break;
				}
			}

		}else{
			error = true;
		}

		// Calculates duration
		duration = micros() - startTime;

		// If error, then doesen't update value
		if(!error)
			distance = duration / 29.0 / 2;
		else
			distance = maxDistance;

		return getDistance();
	}

	/*
		Check if the sensor is connected
	*/
	virtual bool isConnected(){
		sendCommand();
		return waitResponse();
	}

	/*
		Thread implementation
	*/
	virtual void run(){
		readDistance();

		runned();
	}

};

extern PingUltrasonic Ultrasonic;

#endif

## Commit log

2017-07-03 PID Line Follower
2017-07-07 Change contants of PID
2017-07-09 All files of the final version - Marcos John
    [Allen_M3x10.stl, Apoio 2x.STL, Apoio.SLDPRT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]

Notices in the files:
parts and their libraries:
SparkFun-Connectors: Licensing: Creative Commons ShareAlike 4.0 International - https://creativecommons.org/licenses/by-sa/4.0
